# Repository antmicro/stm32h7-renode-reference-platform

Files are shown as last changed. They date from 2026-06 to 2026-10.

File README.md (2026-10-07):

# STM32H7 Renode Reference Platform

Copyright (c) 2026 [Antmicro](https://www.antmicro.com)

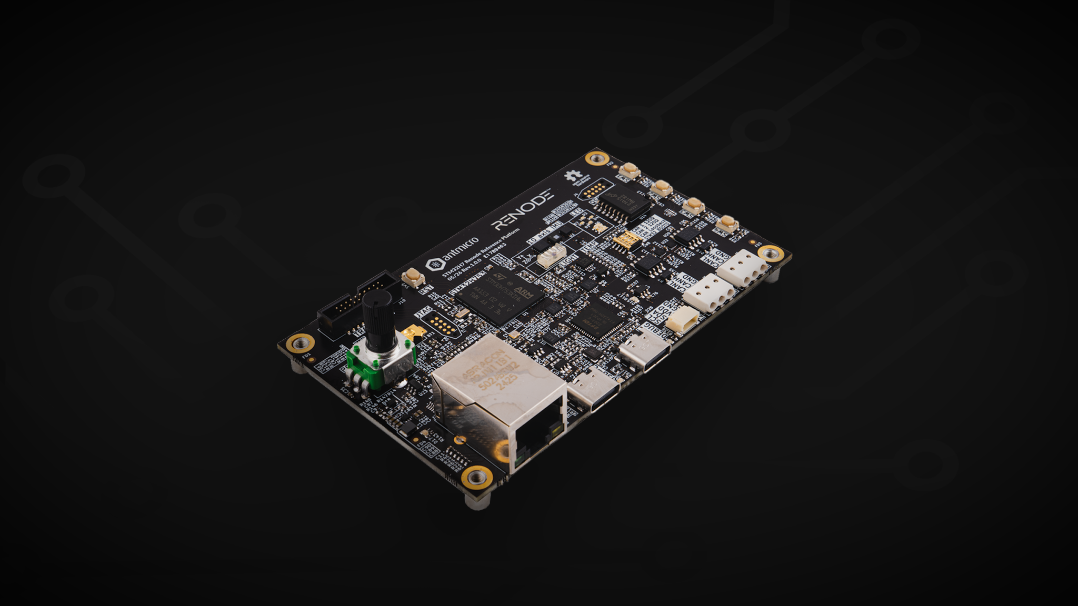
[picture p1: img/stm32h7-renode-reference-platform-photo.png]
Board photo


## Overview

This project contains open hardware design files for an [STM32H7 Renode Reference Platform](https://designer.antmicro.com/library/devices/stm32h7_renode_reference_board). 
The board includes a high-performance 32-bit STM32H753 MCU and a group of sensors integrated into a development kit form factor. 
A digital twin of the board is represented in the [Renode](https://antmicro.com/platforms/renode) simulation framework, allowing users to experiment with and learn how to integrate Renode into the development process.

## Key features

* Powered via USB-C
* Dedicated debug/flashing USB-C port
* 100Mbit/s Ethernet
* DRP USB-C 
* 6-axis IMU
* Power consumption meter
* Temperature sensor
* Light intensity sensor
* 2x CAN bus terminal
* 1Gbit QSPI flash external memory
* QWIIC expansion connector

## Project structure

The main directory contains KiCad PCB project files, the LICENSE, and this README, and the img directory contains graphics for this README.

## Licensing

This project is published under the [Apache-2.0](LICENSE) license.

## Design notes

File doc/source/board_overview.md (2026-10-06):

# Board overview

The STM32H7 Renode Reference Platform is an open hardware board implementing the `STM32H7` MCU family. The board design files were created in KiCad 9.x. A digital twin of the board is represented in the Renode simulation framework, allowing users to experiment with and learn how to integrate Renode into the development process.

You can find out more by visiting the portals listed below:
* [Open Hardware Portal](https://openhardware.antmicro.com/boards/stm32h7-renode-reference-platform/?tab=features)
* [System Designer](https://designer.antmicro.com/library/devices/stm32h7_renode_reference_board?hw-release=rev.1.1.2)
* [GitHub](https://github.com/antmicro/stm32h7-renode-reference-platform)

The [Open Hardware Portal](https://openhardware.antmicro.com/boards/stm32h7-renode-reference-platform/?tab=features) provides 3D renders, a board stackup definition, as well as an interactive preview of the board schematics and layout.

## I/O map

### Buttons, switches, potentiometers

The STM32H7 Renode Reference Platform features multiple buttons and switches allowing the user to interface with the MCU and other board peripherals.
* 4 independent user buttons - `SW1`-`SW4` (mapped in DTS as `sw0`-`sw3`)
* MCU reset button - `SW5`
* CAN bus termination slide switch - `SW8`
* User potentiometer - `POT1`

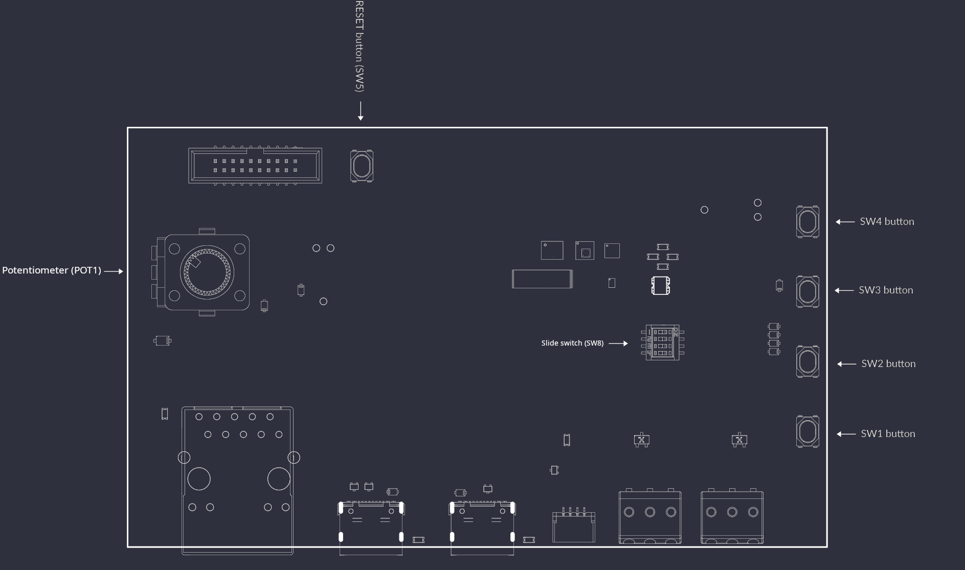
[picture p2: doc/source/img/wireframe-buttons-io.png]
Buttons wireframe


### User LEDs

The board includes multiple LEDs controlled from user space.
* 4 independent green LEDs - `D1`-`D4` (mapped as `pwm-led0`-`pwm-led3`)
* 1 RGB LED - `D5` (mapped as `led0`-`led2` as 3 individual LEDs - red, green and blue)

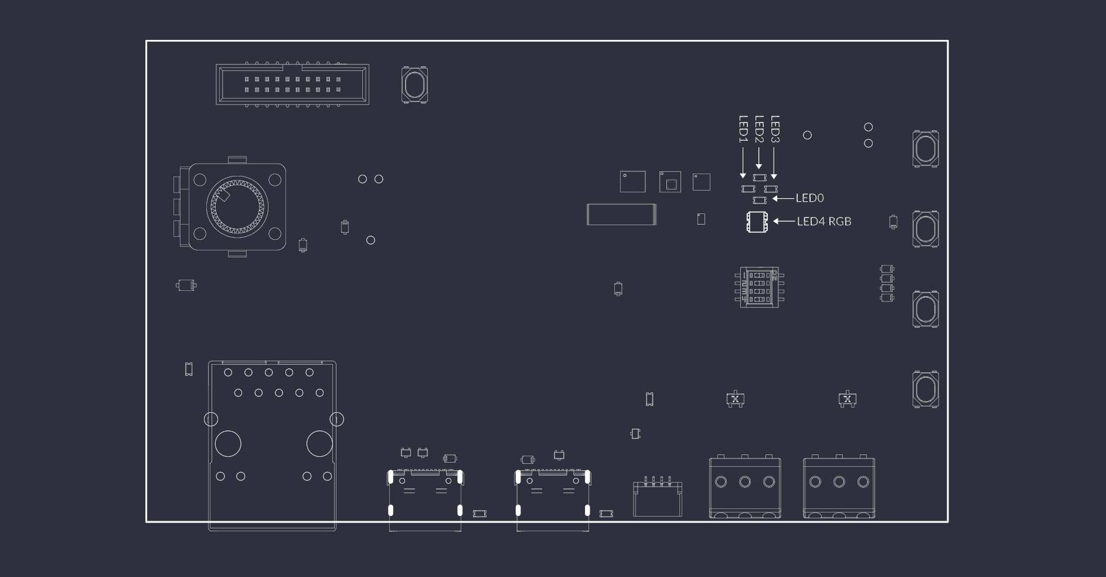
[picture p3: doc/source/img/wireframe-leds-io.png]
LEDs wireframe


### Sensors

The board implements multiple sensors allowing the user to read data about the board's behavior and state.

* 6-axis IMU (Acc + Gyro) - [`LSM6DSO32TR`](https://www.st.com/en/mems-and-sensors/lsm6dso32.html) - `U4`
* 3-axis magnetometer - [`IIS2MDCTR`](https://www.st.com/en/mems-and-sensors/iis2mdc.html) - `U3`
* Barometer - [`LPS25HBTR`](https://www.st.com/en/mems-and-sensors/lps25hb.html) - `U6`
* Temperature sensor - [`TMP108AIYFFR`](https://www.ti.com/product/TMP108/part-details/TMP108AIYFFR) - `U5`
* Light intensity sensor - [`VEML7700`](https://www.vishay.com/en/product/84286/) - `U11`
* Current sensor:
  * [`INA187A2IDBVR`](https://www.ti.com/product/INA187) - `U23`
  * [`INA228AQDGSRQ1`](https://www.ti.com/product/INA228) - `U24`

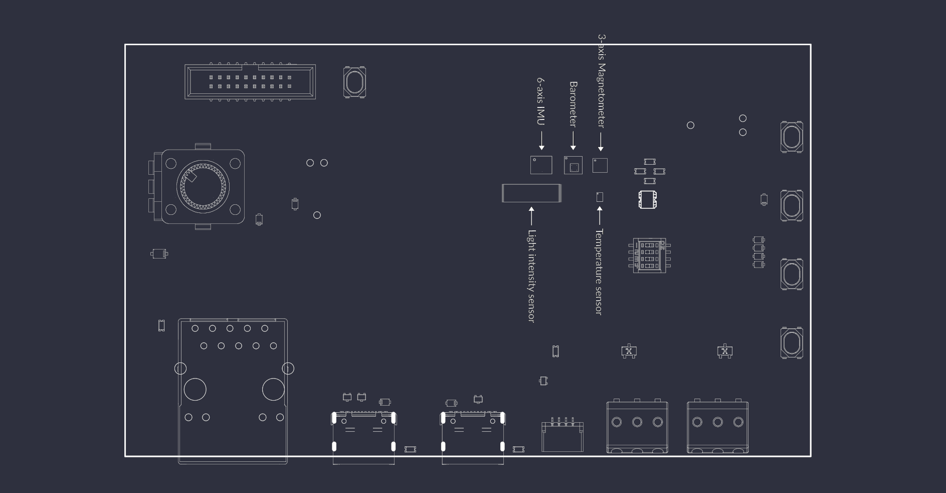
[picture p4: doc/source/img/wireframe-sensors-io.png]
Sensors wireframe


#### I2C address map

All the sensors listed above, except for the current monitors, communicate with the `STM32H7` via the `I2C` protocol on the `i2c-0` bus. `U23` is connected to an `ADC` input of the MCU, while `U24` is reachable over `I2C` only through `FT4232H` (see [Power consumption monitoring](#power-consumption-monitoring)). The `QWIIC` expansion connector (`J8`) is connected to a separate bus.

The `I2C` addresses of the on-board sensors (7-bit) are:
* `LSM6DSO32TR` - `0x6A`
* `IIS2MDCTR` - `0x1E`
* `LPS25HBTR` - `0x5D`
* `TMP108AIYFFR` - `0x48`
* `VEML7700` - `0x10`

The map below shows the addresses occupied on the `i2c-0` bus.

```
  |      0    1    2    3    4    5    6    7    8    9    A    B    C    D    E    F  |
--|------------------------------------------------------------------------------------|
00|     --   --   --   --   --   --   --   --   --   --   --   --   --   --   --   --  |
10|     10   --   --   --   --   --   --   --   --   --   --   --   --   --   1e   --  |
20|     --   --   --   --   --   --   --   --   --   --   --   --   --   --   --   --  |
30|     --   --   --   --   --   --   --   --   --   --   --   --   --   --   --   --  |
40|     --   --   --   --   --   --   --   --   48   --   --   --   --   --   --   --  |
50|     --   --   --   --   --   --   --   --   --   --   --   --   --   5d   --   --  |
60|     --   --   --   --   --   --   --   --   --   --   6a   --   --   --   --   --  |
70|     --   --   --   --   --   --   --   --   --   --   --   --   --   --   --   --  |
```

### Connectors

The board implements multiple connectors allowing the user to interface with the board and attach auxiliary devices.

* USB-C DEBUG - `J1`
* USB-C user - `J2`
* Ethernet - `J3`
* QSPI flash access - `J4`
* CAN bus - `J5`, `J6`
* QWIIC I2C expansion - `J8`
* Trace and JTAG - `J10`

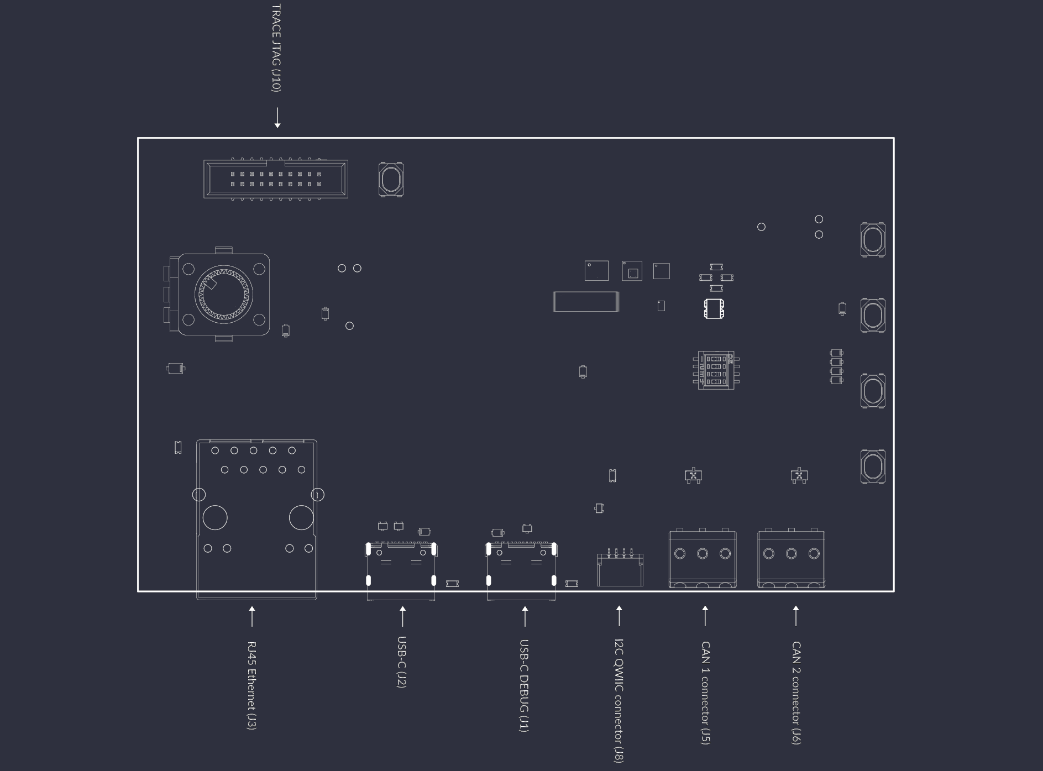
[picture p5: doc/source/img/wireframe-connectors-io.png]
Connectors wireframe


## CAN bus

The STM32H7 Renode Reference Platform is equipped with two separate CAN FD `TCAN3414DR` transceivers. With `SW8` you can manipulate CAN termination.
Apart from the CAN bus termination, you can also connect the two buses together to use them as a loopback interface.

For `SW8` switching logic, refer to the table below. An exact connection diagram can be found in the IOs schematic sheet.

| Channel number | Channel function | OFF | ON |
| --- | --- | --- | -- |
| 1 | CAN bus 1 termination | Disabled | Enabled |
| 2 | CAN bus 2 termination | Disabled | Enabled |
| 3 | CAN bus 1 to CAN bus 2 loopback | Disabled | Enabled |

Connecting to the CAN bus with auxiliary devices can be done with the `J5` and `J6` `WAGO_2059` connectors. These connectors allow standard prototyping cables to be connected without any additional tools.

```{note}
Remember to tie GND with devices connected to the CAN bus transceivers to avoid a floating ground or unexpected ground loops.
```

## BOOT0 switch

The 4th channel of the `SW8` dip switch controls the BOOT0 signal. The BOOT0 pin determines the memory source from which the MCU boots after reset. When BOOT0 = OFF, it normally boots your program from Flash, and when BOOT0 = ON, it can boot the built-in System Memory bootloader.

## User USB

The `J2` USB connector is configured as an endpoint. The `USB-C` connector is used to connect the board to a USB host, such as a PC. It can be used for functions such as virtual COM port communication, firmware updates, or other USB device applications.

## Power

The STM32H7 Renode Reference Platform is powered via the `J1` (`USB-C DEBUG`) connector. Plug the board into a standard PC USB slot or power it via a USB-C charger.

```{note}
To power the board from the `J2` (`USB-C`) connector instead, remove the `R1` resistor and populate the `R2` resistor. Both positions use 0 Ohm 0402 resistors.
```

### Power consumption monitoring

The board is able to monitor its power consumption via two independent current monitors.

`U23` `INA187` is connected to the `STM32H753` analog input and feeds information into the firmware running on the MCU.

`U24` gives you the ability to read the power consumption directly from the host device via the `USB-C DEBUG` port, eliminating the need for external measuring devices. It can be accessed via the `FT4232H` channel B as an `I2C` device. You can follow the [FTDI Guide](https://ftdichip.com/Documents/AppNotes/AN_113_FTDI_Hi_Speed_USB_To_I2C_Example.pdf) for more information on interfacing with the `I2C` bus and learn more about the PyFtdi Python library from the [project documentation](https://eblot.github.io/pyftdi/).

## Flashing

There are 3 options to flash firmware into the MCU.

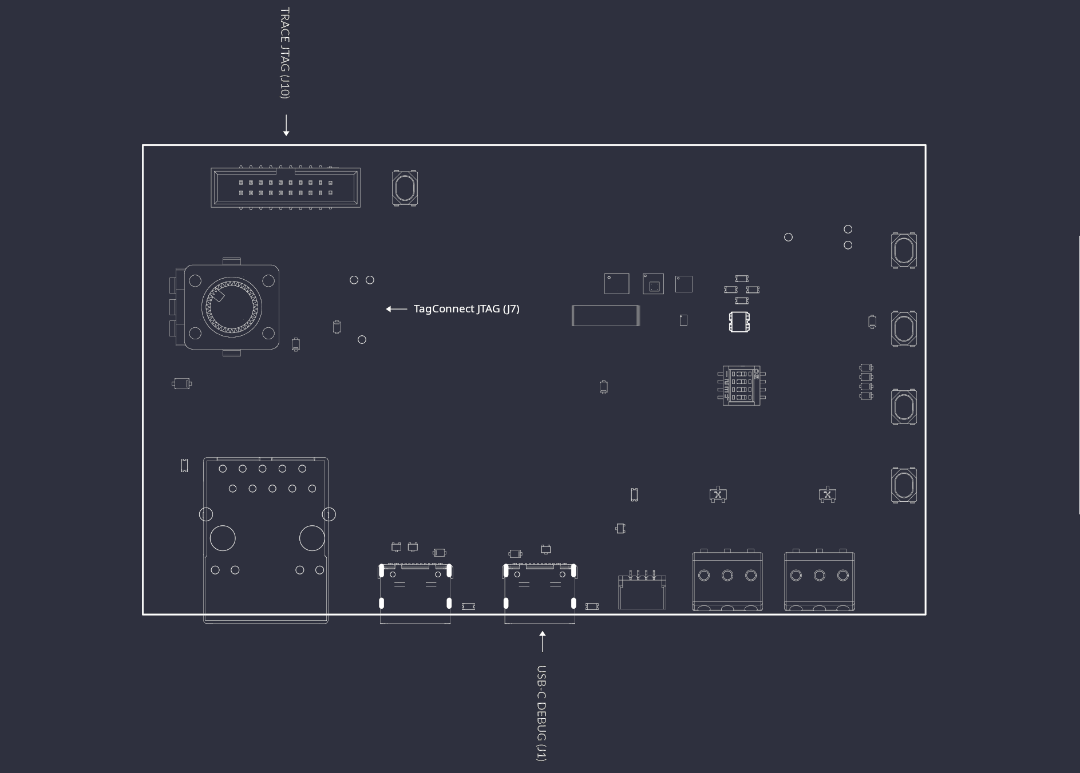
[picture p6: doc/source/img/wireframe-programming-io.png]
Programming connectors wireframe


### FTDI (`FT4232H`)

The main flashing interface of the board is the [FTDI `FT4232H`](https://ftdichip.com/wp-content/uploads/2024/05/DS_FT4232H.pdf) USB bridge. This chip is connected to the `USB-C DEBUG` port and exposes a JTAG interface for programming and debugging of the MCU.

Flashing via the `FT4232H` chip is described in the [Flash the board](getting_started.md#flash-the-board) chapter.

### 10-pin Tag-Connect

An alternative programming method is available via the [10-pin Tag-Connect](https://www.tag-connect.com/info) terminal (`J7`). An off-the-shelf `TC2050-IDC-NL` Tag-Connect cable can be used with most commercially available programmers, giving developers extra flexibility when working with the STM32H7 Renode Reference Platform. We recommend using the Tag-Connect with Antmicro's [Debug Toolkit](https://openhardware.antmicro.com/boards/debug-toolkit/?tab=features).

```{note}
Note that `J7` is not to be confused with `J4`, the Tag-Connect terminal that provides access to the QSPI flash.
```

The `J7` Tag-Connect pinout is described in the table below:

| Signal name | Pin | Pin | Signal name |
| --- | --- | --- | --- |
| `3V3` | 1 | 10  | `JTAG nRST` |
| `JTAG TMS`  | 2 | 9 | `GND` |
| `GND` | 3 | 8 | `JTAG TDI`  |
| `JTAG TCK`  | 4 | 7 | `nc` |
| `GND` | 5 | 6 | `JTAG TDO`  |

```{note}
Remember to supply power to the board before flashing, as the programming connector does not provide power to the device.
```

### 19-pin JTAG/SWD and Trace Connector

The third way to flash the `STM32H753` MCU is via a standardized [19-pin JTAG/SWD and Trace Connector](https://kb.segger.com/19-pin_JTAG/SWD_and_Trace_Connector) (`J10`). This type of connector is widely used in `J-Trace Pro` programmers. Additionally, it gives access to the trace debug interface, with 4 trace data lines exposed.

The `J10` JTAG/SWD and Trace connector pinout is described in the table below:

| Signal name | Pin | Pin | Signal name |
| --- | --- | --- | --- |
| `MCU_VDDA` | 1 | 2 | `JTAG TMS` |
| `GND` | 3 | 4 | `JTAG TCK` |
| `GND` | 5 | 6 | `JTAG TDO` |
| `nc` | 7 | 8 | `JTAG TDI` |
| `GND` | 9 | 10  | `JTAG nRST` |
| `GND` | 11  | 12  | `TRACE CLK` |
| `GND` | 13  | 14  | `TRACE DATA0`  |
| `GND` | 15  | 16  | `TRACE DATA1`  |
| `GND` | 17  | 18  | `TRACE DATA2`  |
| `GND` | 19  | 20  | `TRACE DATA3`  |

```{note}
Remember to supply power to the board before flashing, as the programming connector does not provide power to the device.
```

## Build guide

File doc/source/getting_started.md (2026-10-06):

# Getting started guide

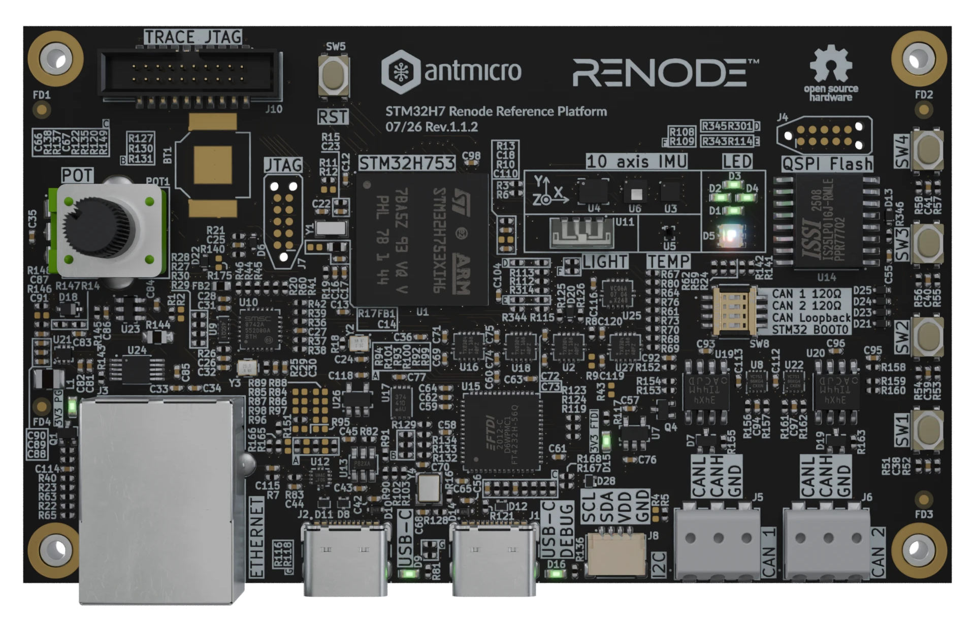
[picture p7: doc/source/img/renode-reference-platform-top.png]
STM32H7 Renode Reference Platform hardware


This manual will guide you through the initial setup of the open hardware STM32H7 Renode Reference Platform.

For the board layout and the location of the connectors and buttons mentioned here, see the [Board overview](board_overview.md) chapter. For background on the Zephyr target used below, see the [Zephyr documentation](https://docs.zephyrproject.org/latest/boards/antmicro/stm32h7_renode_reference_board/doc/index.html).

## Collect the hardware

* The STM32H7 Renode Reference Platform board
* A host PC running Linux (the instructions in this guide were verified with a Debian-based system)
* USB-C cable to connect PC with the STM32H7 Renode Reference Platform board

## Connect the board

Plug the USB-C cable into the `USB-C DEBUG` port and connect the other end to your PC. The board powers up through this port. This single connection powers the board and provides flashing, debugging and the debug console at the same time.

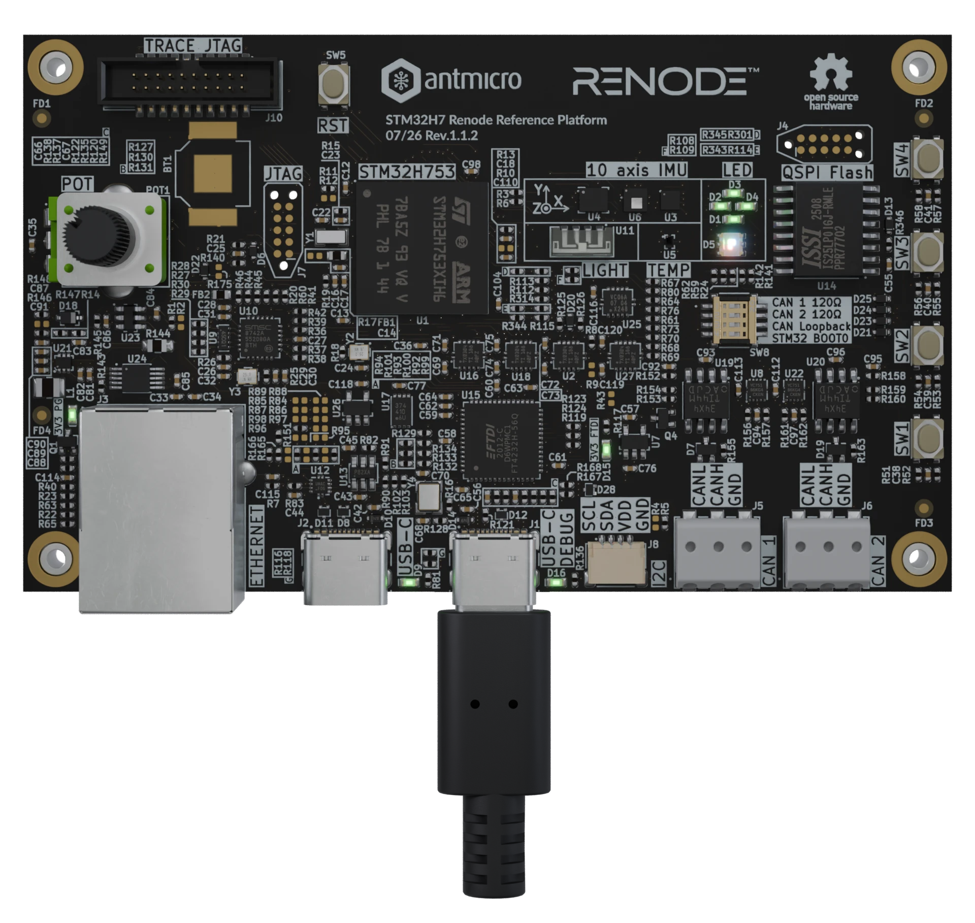
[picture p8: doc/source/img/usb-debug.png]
USB-C DEBUG


Confirm that the PC detects the board's FTDI bridge with `lsusb`. The output must contain:

```
Bus 001 Device 008: ID 0403:6011 Future Technology Devices International, Ltd FT4232H Quad HS USB-UART/FIFO IC
```

## Set up the demo workspace and flash the board

The demo application lives in the [stm32h7-renode-reference-platform-zephyr](https://github.com/antmicro/stm32h7-renode-reference-platform-zephyr) repository. 
It allows you to experiment with basic functionalities of the board.

Clone the demo repository:

```
git clone https://github.com/antmicro/stm32h7-renode-reference-platform-zephyr
```

Then follow the `Quick start` instructions in [the demo's README](https://github.com/antmicro/stm32h7-renode-reference-platform-zephyr#quick-start) to set up the `West` build management tool together with Zephyr requirements, and to flash the board with the built `stm32h7_renode_reference_board` target.

## Open the debug console

The Zephyr example provides a console log that allows the user to easily identify if the firmware is flashed correctly into the MCU. 
The STM32H7 Renode Reference Platform provides console access on the serial port. We suggest using `picocom` for console monitoring while flashing the device.

First, you need to identify the proper COM port. Check the detected USB devices in `dmesg`:

```
$ sudo dmesg | grep FTDI
[90522.076308] usb 1-4: Manufacturer: FTDI
[90522.133565] usbserial: USB Serial support registered for FTDI USB Serial Device
[90522.133630] ftdi_sio 1-4:1.0: FTDI USB Serial Device converter detected
[90522.133882] usb 1-4: FTDI USB Serial Device converter now attached to ttyUSB0
[90522.133932] ftdi_sio 1-4:1.1: FTDI USB Serial Device converter detected
[90522.134117] usb 1-4: FTDI USB Serial Device converter now attached to ttyUSB1
[90522.134175] ftdi_sio 1-4:1.2: FTDI USB Serial Device converter detected
[90522.134402] usb 1-4: FTDI USB Serial Device converter now attached to ttyUSB2
[90522.134440] ftdi_sio 1-4:1.3: FTDI USB Serial Device converter detected
[90522.134630] usb 1-4: FTDI USB Serial Device converter now attached to ttyUSB3

```

In the case presented above, the `ftdi_sio 1-4:1.2:` device is attached to `ttyUSB2`. To monitor the console, use:

```
sudo picocom -b 115200 /dev/ttyUSB2
```

After connecting to the console and resetting the device, you should see a log similar to the following:

```
$ sudo picocom -b 115200 /dev/ttyUSB2

[00:00:00.050,000] <inf> phy_mii: PHY (0) ID 7C131
[00:00:00.122,000] <inf> LSM6DSO: Initialize device lsm6dso@6a
[00:00:00.122,000] <inf> LSM6DSO: chip id 0x6c
*** Booting STM32H7 Renode Platform Demo c605ea46e15f ***
demo:~$
```

## Blink the LEDs

Enter the following commands in the demo shell:

```
led blink pwmleds 0 500
led blink pwmleds 1 500
led blink pwmleds 2 500
```

The three green LEDs `D1`-`D3` blink with a 500 ms period.

## Running the digital twin in Renode

A digital twin of the board is available in the [Renode](https://renode.io) simulation framework. It models the `STM32H753` MCU together with the on-board peripherals.

The twin is published as part of Zephyr: the [`stm32h7_renode_reference_board` target](https://github.com/zephyrproject-rtos/zephyr/tree/main/boards/antmicro/stm32h7_renode_reference_board) ships the Renode platform description (`stm32h7_renode_reference_board.repl`) and the Renode script (`stm32h7_renode_reference_board.resc`) in its `support` directory. The script creates the simulated board, loads the demo binary and opens a terminal on the simulated USART2 console.

Because Renode is the default emulator of this Zephyr target, the demo built in [Flash the board](#flash-the-board) runs on the digital twin with one command, from the same directory:

```
west simulate
```

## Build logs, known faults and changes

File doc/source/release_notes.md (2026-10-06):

# Revision changelog

## 1.1.2 
  
* Bump project to KiCAD 10
* Reduce RGB LEDs intensity
* Minor adjustment for footprints

## 1.1.1

* Replace QSPI flash with `IS25LP01GJ-RMLE`
* Add testpoints for JTAG

## 1.1.0

Revision 1.1.0 fixes known bugs in the initial 1.0.0 revision. Main changes include:
* Fix signal directions for JTAG signal buffers
* Reduce RGB LED intensity
* Fix UART crossed signals on `FT4232H`
* Replace RTC battery socket, set as DNP
* Fix `U21` PG LED
* Optimize BOM
* Disconnect MCU from `FT4232H` reset, set as DNP

## 1.0.0

Initial revision.

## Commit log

2026-04-03 Add kicad project stub
    [.kicad_pcb, .kicad_sch]
2026-04-07 [#94620] Add basic PCB components
    [.kicad_pcb, .kicad_sch, renode-reference-platform.kicad_pcb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]
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2026-04-07 [#94620] Add port markings
    [renode-reference-platform.kicad_pcb]
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2026-04-08 [#94684] Add ports to subsheets
    [debug-usb-c.kicad_sch, eth.kicad_sch, imu.kicad_sch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]
2026-04-08 [#94684] Revise component placement
    [mcu.kicad_sch, renode-reference-platform.kicad_pcb, renode-reference-platform.kicad_sch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]
2026-04-08 [#94620] Add RPI expansion marking
    [renode-reference-platform.kicad_pcb]
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2026-04-08 [#94727] Basic mcu connections
    [mcu.kicad_sch]
2026-04-09 [#94727] Add RMII, IOs, JTAG, UART, QSPI connection to MCU
    [eth.kicad_sch, mcu.kicad_sch, renode-reference-platform.kicad_sch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]
2026-04-09 [94727] Add remaining I2C buses
    [mcu.kicad_sch, renode-reference-platform.kicad_sch, rpi-expansion.kicad_sch]
2026-04-09 [94727] Reconnect buses to MCU to sovle overlaping signals
    [mcu.kicad_sch, renode-reference-platform.kicad_sch]
2026-04-10 [#94727] Redraw RPI markings
    [pmod.kicad_sch, renode-reference-platform.kicad_pcb]
2026-04-10 [#94833] Replace RJ45 socket
    [renode-reference-platform.kicad_pcb]
2026-04-10 [#94823] Add ethernet implementation
    [eth.kicad_sch]
2026-04-10 [#94823] Add RMII termination
    [mcu.kicad_sch, renode-reference-platform.kicad_sch]
2026-04-10 [#94862] Add PMOD interfaces
    [pmod.kicad_sch, renode-reference-platform.kicad_sch]
2026-04-13 [#94883] LED and pushbutton schematic
    [ios.kicad_sch]
2026-04-13 [#94911] Add USB DRP
    [renode-reference-platform.kicad_sch, usb-c.kicad_sch]
2026-04-13 [#94940] Add magnetometer and acc+gyro
    [imu.kicad_sch]
2026-04-13 [#94940] Add barometer and temperature sensors
    [imu.kicad_sch]
2026-04-14 [#94972] Add QSPI flash
    [renode-reference-platform.kicad_sch, spi-flash.kicad_sch]
2026-04-14 [#94972] Reconnect QSPI to MCU
    [mcu.kicad_sch, renode-reference-platform.kicad_sch]
2026-04-14 [#94728] Add current measurement and DCDC converter
    [power.kicad_sch]
2026-04-15 [#95008] Connect ESD protection and CC1/2 resistors to USB-C debug
    [debug-usb-c.kicad_sch]
2026-04-15 [#95008] Change USB-C data lines ESD protection
    [usb-c.kicad_sch]
2026-04-15 [#95008] Connect power to the FTDI, connect USB data, crystal resonator and misc signals
    [debug-usb-c.kicad_sch]
2026-04-15 [#95008] Connect JTAG and UART buses to the FTDI
    [debug-usb-c.kicad_sch]
2026-04-15 [#95008] Change FTDI to FT4232H-56Q-REEL, add I2C
    [debug-usb-c.kicad_sch]
2026-04-15 [#95008] Connect JTAG, I2C and UART via level shifters, to avoid backfeeding
    [debug-usb-c.kicad_sch]
2026-04-15 [#95008] Add EEPROM to FTDI chip
    [debug-usb-c.kicad_sch]
2026-04-15 [#95036] Rename PMOD signals
    [pmod.kicad_sch, renode-reference-platform.kicad_sch]
2026-04-15 [#95036] Reconnect power flags, add GPIOs to RPI connector
    [power.kicad_sch, renode-reference-platform.kicad_sch, rpi-expansion.kicad_sch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]
2026-04-15 [#95036] Reconnect IMU interupts
    [imu.kicad_sch, power.kicad_sch, renode-reference-platform.kicad_sch]
2026-04-15 [#95036] Manage I2C, UART, SPI interfaces for RPI and PMOD connectors
    [debug-usb-c.kicad_sch, mcu.kicad_sch, renode-reference-platform.kicad_sch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]
2026-04-15 [#95036] Add missing interfaces to MCU sheet
    [mcu.kicad_sch, renode-reference-platform.kicad_sch]
2026-04-15 [#95036] Add CAN bus placeholders
    [can.kicad_sch, mcu.kicad_sch, renode-reference-platform.kicad_sch]
2026-04-15 [#95036] Start connecting RPI signals to MCU
    [mcu.kicad_sch, renode-reference-platform.kicad_sch]
2026-04-16 [#95036] Connect PWM capable outputs of STM32
    [mcu.kicad_sch]
2026-04-16 [#95036] Connect PMOD pins to MCU
    [mcu.kicad_sch, pmod.kicad_sch, rpi-expansion.kicad_sch]
2026-04-16 [#95036] Connect remaining pins to MCU
    [mcu.kicad_sch]
2026-04-16 [#95036] Add CAN bus subsheet
    [can.kicad_sch, debug-usb-c.kicad_sch, mcu.kicad_sch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]
2026-04-16 [#95036] Add pullups to I2C
    [mcu.kicad_sch]
2026-04-16 [#95036] Rearrange MCU scheet
    [mcu.kicad_sch]
2026-04-16 [#95036] Adjust MCU LSE clock
    [mcu.kicad_sch]
2026-04-16 [#95036] Solve basic ERCs
    [can.kicad_sch, debug-usb-c.kicad_sch, eth.kicad_sch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]
2026-04-17 [#95036] Replace barometer IC
    [imu.kicad_sch, mcu.kicad_sch, renode-reference-platform.kicad_sch]
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2026-04-17 [#95036] Fix hierarchical ports directions, add CAN termination jumper
    [can.kicad_sch, imu.kicad_sch, mcu.kicad_sch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]
2026-04-17 [#95036] Update block diagram
    [renode-reference-platform.kicad_sch]
2026-04-17 [#95036] Fix MCU pin attachment
    [mcu.kicad_sch]
2026-04-17 [#95036] Add schematic markings
    [can.kicad_sch, eth.kicad_sch, ios.kicad_sch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]
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2026-04-17 [#95036] Add CAN Bus connector to board
    [renode-reference-platform.kicad_pcb]
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2026-04-21 [#95398] Align connectors, place basic USB C components
    [renode-reference-platform.kicad_pcb]
2026-04-21 [#95398] Add LED driving components and CAN Bus
    [renode-reference-platform.kicad_pcb]
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2026-04-22 [#95398] Replace reset button
    [mcu.kicad_sch, renode-reference-platform.kicad_pcb]
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2026-04-23 [#95398] Replace CAN connectors
    [can.kicad_sch, mcu.kicad_sch]
2026-04-23 [#95398] Replace WAGO connectors
    [can.kicad_sch]
2026-04-23 [#95398] Update WAGO symbols. Add CAN 3V3 compatibility comment
    [can.kicad_sch]
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2026-04-30 [#95451] Improve placement. Add JTAG TC and ID EEPROM.
    [can.kicad_sch, debug-usb-c.kicad_sch, ios.kicad_sch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]
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2026-05-15 [#95451] Post review fixes
    [can.kicad_sch, debug-usb-c.kicad_sch, eth.kicad_sch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]
2026-05-20 [#97180] Replace solderable battery with battery holder
    [mcu.kicad_sch]
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2026-06-16 [#98576] Replace RGB LED resistors with 1k
    [ios.kicad_sch]
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2026-06-16 [#98588] Replace RTC battery
    [mcu.kicad_sch]
2026-06-16 [#98579] Fix PG LED logic and add LED description
    [power.kicad_sch]
2026-06-16 [#98575] Fix FTDI buffers
    [debug-usb-c.kicad_sch]
2026-06-16 [#98575] Swap FTDI buffers
    [debug-usb-c.kicad_sch]
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2026-06-19 [#98579] Replace battery connector
    [mcu.kicad_sch]
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2026-07-08 [#100413] Change QSPI-Flash to IS25LP01GJ-RMLE, Update pull-ups to FLASH_PWR rail
    [spi-flash.kicad_sch]
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2026-07-15 Update push button and VEML footprints from lib
    [ios.kicad_sch, mcu.kicad_sch]
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2026-07-31 [#102004] Change RGB LED resistors - rotate resistors
    [can.kicad_sch, debug-usb-c.kicad_sch, eth.kicad_sch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]
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
